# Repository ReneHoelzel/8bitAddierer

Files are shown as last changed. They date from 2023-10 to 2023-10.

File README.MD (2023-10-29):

# 8bit Addierer

Das Projekt wurde in Zusammenarbeit mit dem Zuseum in Bautzen entwickelt und soll Schülern und interessierten die Rechenweise eine Computers anhand eines Bytes (=8bit) veranschaulichen. 

## Aufbau

Im unteren Bereich befindet sich ein Arduino Nano V3 als Steuereinheit sowie 8x Doppelpins an die je ein Taster angeschlossen werden kann. Ein Anschlus für den neunten Taster (Erläterung siehe Funktion) befindet sich unter dem Arduino.<br/>

## Funktion

Mit den 8 Tastern kann die dazugehörige 7-Segment Anzeige/rote LED jeweils ein- oder ausgeschalten werden. Je nachdem welche "Bits" eingeschalten sind wird oben in der 3-stelligen Anzeige der entsprechende Wert als Ganzzahl (Byte) ausgegeben.

Zum Beispiel: 0 0 0 0 1 0 0 1 entspricht dem Wert 9.

Mit dem neunten Taster kann das Ergebnis "ausgeblendet" werden (es wird der Wert 999 angezeigt). Dies kann verwendet werden, um einen Wert einzustellen und die Schüler herausfinden zu lassen welcher Byte-Wert sich dahinter verbirgt.

<br/>

<span style="color:red;">Die Verwendung erfolgt auf eigene Gefahr.<span/>

Zum Arduino Programm geht es [hier](https://github.com/ReneHoelzel/8bitAddierer/tree/main/Program).

Es gibt aktuell 2 Board Revisionen:

- [Revision A](8BitZahlAnzeige_RevA/README.MD)

- [Revision B](8BitZahlAnzeige_RevB/README.MD)

Der Unterschied zu beiden Versionen ist, dass bei Revision B die 8x 7-Segment Anzeige und der MAX7219 Steuerchip die Positionen getauscht haben.

## ToDo

- Gehäuse entwerfen

- Animation der 3-stelligen Anzeige, wenn der neunte Taster gedrückt ist.

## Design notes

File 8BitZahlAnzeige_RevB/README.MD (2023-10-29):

# 8bit Addierer

##### Revision B

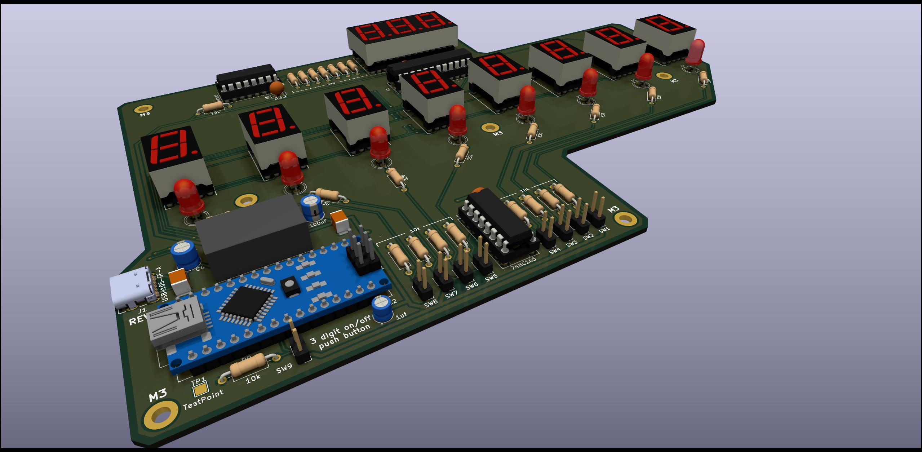
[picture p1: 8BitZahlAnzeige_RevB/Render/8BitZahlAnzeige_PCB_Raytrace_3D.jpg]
3D Ansicht


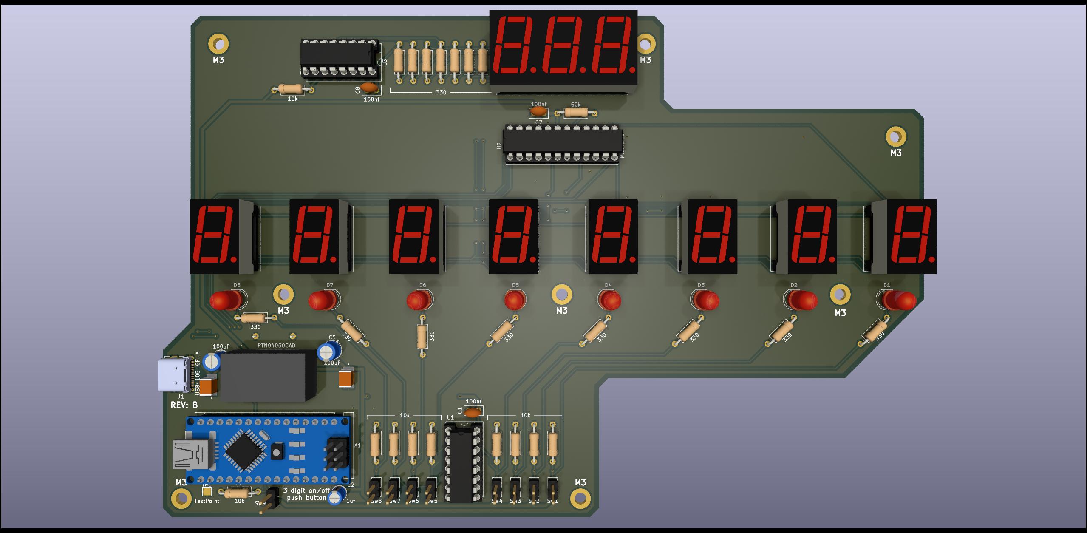
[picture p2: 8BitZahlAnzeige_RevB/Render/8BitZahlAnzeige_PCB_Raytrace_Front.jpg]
Front Ansicht bestückt Vorderseite bestückt


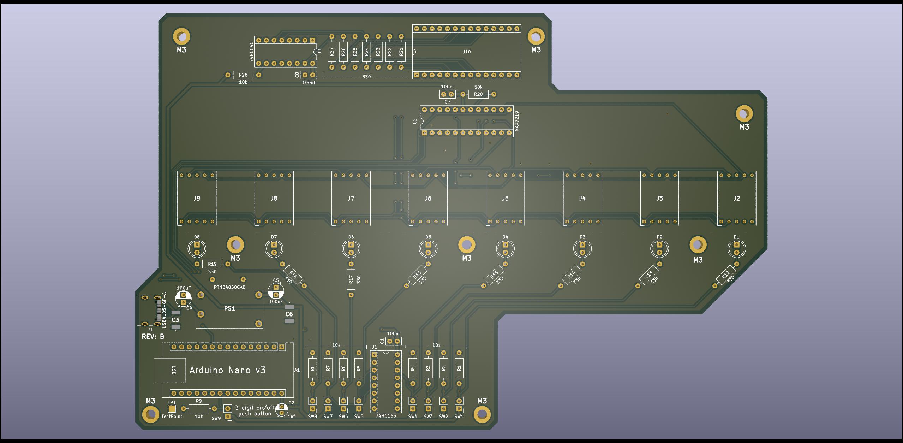
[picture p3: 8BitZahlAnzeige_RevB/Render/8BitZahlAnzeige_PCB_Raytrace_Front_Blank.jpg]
Vorderseite


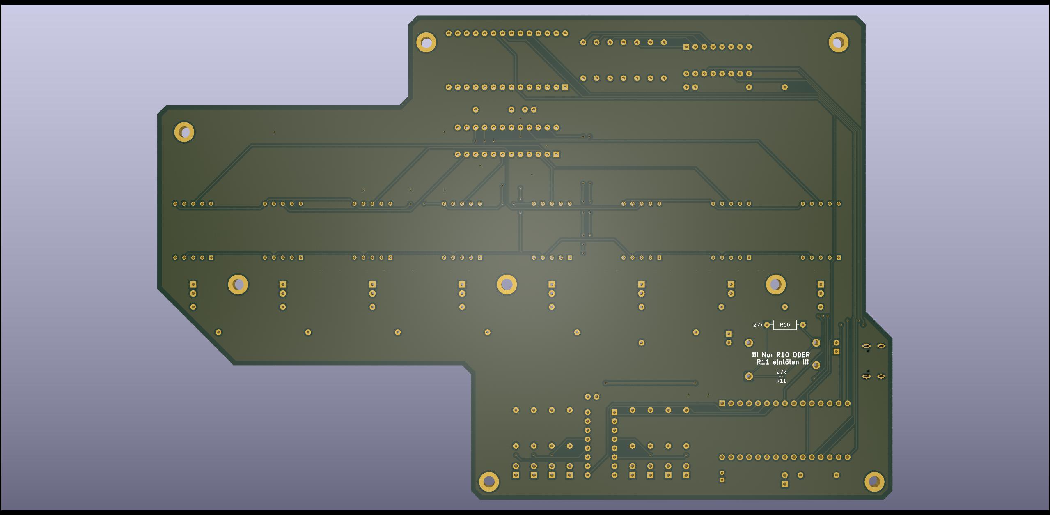
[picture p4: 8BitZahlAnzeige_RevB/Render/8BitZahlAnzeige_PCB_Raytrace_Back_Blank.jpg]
Rückseite 3D Rückseite


[Zurück zur Startseite](https://github.com/ReneHoelzel/8bitAddierer/tree/main)

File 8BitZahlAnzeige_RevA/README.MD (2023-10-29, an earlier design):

# 8bit Addierer

##### Revision A

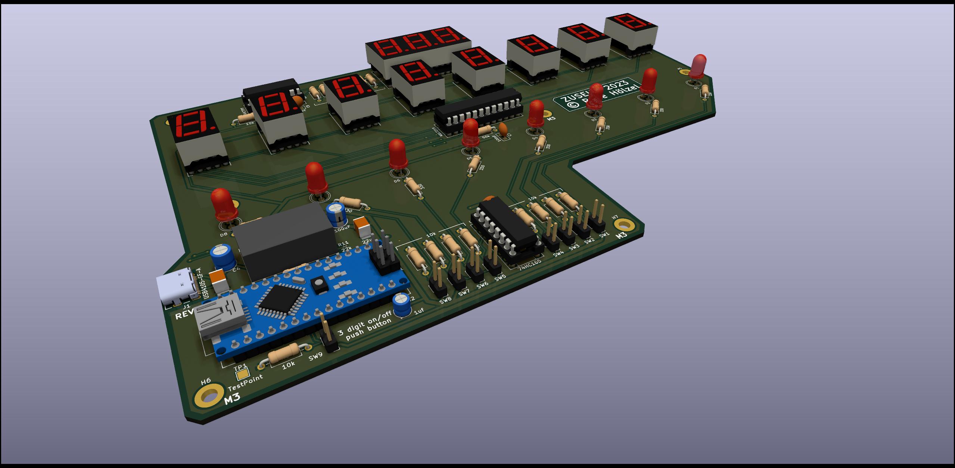
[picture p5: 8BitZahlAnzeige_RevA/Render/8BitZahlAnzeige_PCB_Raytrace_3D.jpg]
3D Ansicht bestückt


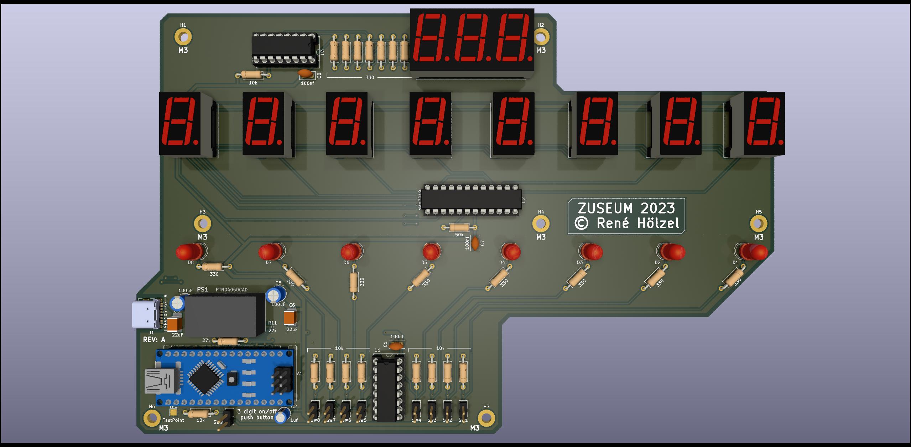
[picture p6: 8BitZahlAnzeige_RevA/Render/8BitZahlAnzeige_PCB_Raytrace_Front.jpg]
Front Ansicht bestückt


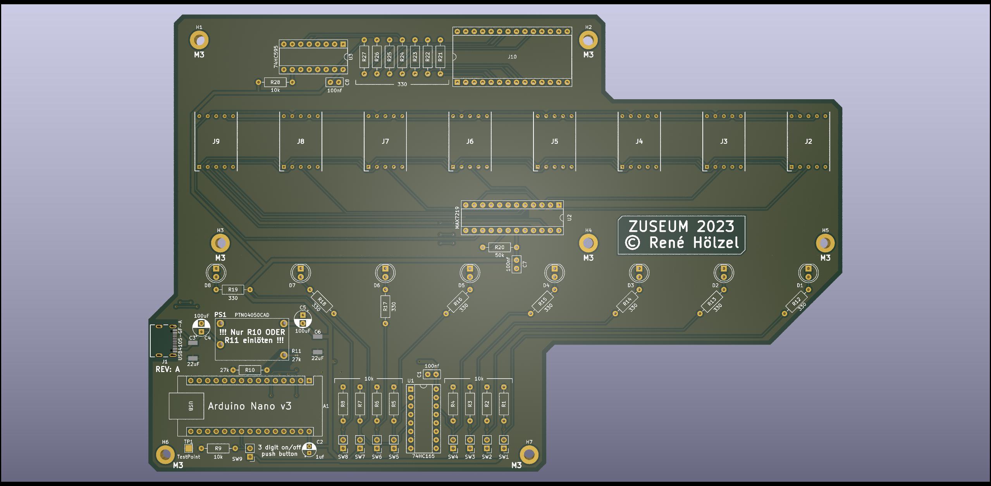
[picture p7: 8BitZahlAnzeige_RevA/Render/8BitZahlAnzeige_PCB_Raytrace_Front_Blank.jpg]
Vorderseite Frontansicht


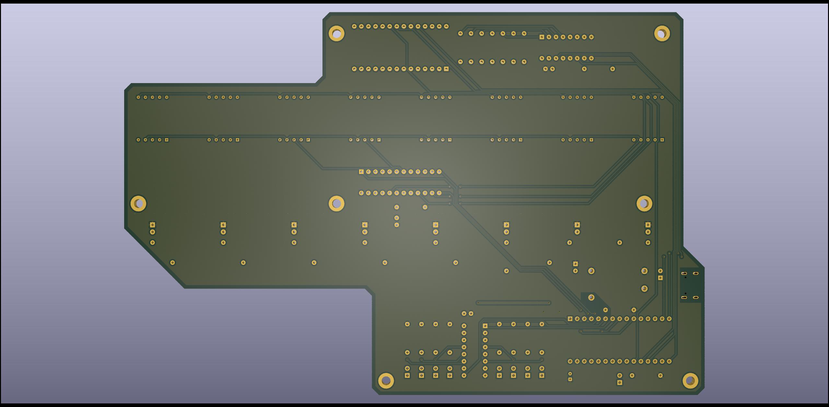
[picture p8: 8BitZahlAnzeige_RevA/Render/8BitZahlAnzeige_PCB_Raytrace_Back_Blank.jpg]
Rückseite Rückansicht


[Zurück zur Startseite](https://github.com/ReneHoelzel/8bitAddierer/tree/main)

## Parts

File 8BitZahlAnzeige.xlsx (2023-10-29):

Anzahl Platinen: | 6
Anzahl pro Platine | Anzahl benötigt gesamt | Referenz auf Platine | Bezeichnung | Verpackung Menge | Verpackung Preis | Gesamtpreis | Beispiel Bild | Link | Lieferant | Bestellt Anzahl | Bestellt Preis
1 | 6 | A1 | Arduino Nano v3 | 3 | 19.79 € | 39.58 € |  | https://www.amazon.de/3Pack-MEGA328P-AU-Micro-Controller-Entwicklungsboard-USB-Kabel/dp/B0C4H3LXKN | Amazon | 2 | 48.48 €
9 | 54 | SW1, SW2, SW3, SW4, SW5, SW6, SW7, SW8, SW9 | Drucktaster | 20 | 9.65 € | 28.95 € |  | https://www.amazon.de/gp/product/B0BY12RR6Z | Amazon | 2 | 28.20 €
1 | 6 | U1 | 74HC165 | 10 | 19.91 € | 19.91 € |  | https://www.amazon.de/gp/product/B0CBP8VNW3 | Amazon | 0 | 8.90 €
1 | 6 | U2 | MAX7219 | 10 | 36.33 € | 36.33 € |  | https://www.amazon.de/gp/product/B07FW17ZW8/ref=ppx_od_dt_b_asin_title_s00?ie=UTF8&psc=1 | Amazon | 0 | 8.90 €
1 | 6 | U3 | 74HC595 | 10 | 6.50 € | 6.50 € |  | https://www.amazon.de/HeyNana-SN74HC595N-Register-74HC595-DIP-16/dp/B093Y2MQGV | Amazon | 0 | 8.90 €
9 | 54 | SW1, SW2, SW3, SW4, SW5, SW6, SW7, SW8, SW9 |  | 80 | 1.00 € | 1.00 € |  | https://www.amazon.de/gp/product/B07VGF34KX/ref=ppx_yo_dt_b_asin_title_o07_s00?ie=UTF8&psc=1 | Amazon | 0 | 8.90 €
1 | 6 | J1 |  | 1 | 0.95 € | 5.70 € |  | https://www.amazon.de/gp/product/B09JZX2SBL | Amazon | 4 | 12.70 €
8 | 48 | J2, J3, J4, J5, J6, J7, J8, J9 |  | 10 | 9.30 € | 46.50 € |  | https://www.amazon.de/gp/product/B07CLCC82N | Amazon | 3 | 36.80 €
3 | 18 | C1, C7, C8 | 100nf (=0,1uF) | 1 | 0.13 € | 2.34 € |  | https://www.conrad.de/de/p/weltron-keramik-kondensator-radial-bedrahtet-0-1-f-50-v-dc-20-b-x-h-5-08-mm-x-5-08-mm-1-st-453358.html | Conrad | 20 | 11.50 €
1 | 6 | C2 | 1uf | 1 | 0.04 € | 0.26 € |  | https://www.conrad.de/de/p/teapo-kss105m063s1a5b07k-elektrolyt-kondensator-radial-bedrahtet-1-5-mm-1-f-6-3-v-20-o-x-h-4-mm-x-7-mm-1-st-1325878.html | Conrad | 0 | 8.90 €
2 | 12 | C4, C5 | 100uF | 1 | 0.06 € | 0.78 € |  | https://www.conrad.de/de/p/teapo-ksy107m025s1a5e11k-elektrolyt-kondensator-radial-bedrahtet-2-5-mm-100-f-25-v-10-o-x-h-6-3-mm-x-11-mm-1-st-1301761.html | Conrad | 12 | 9.68 €
8 | 48 | D1, D2, D3, D4, D5, D6, D7, D8 | LED | 1 | 0.13 € | 6.24 € |  | https://www.conrad.de/de/p/tru-components-1573741-led-bedrahtet-rot-rund-5-mm-1300-mcd-50-20-ma-2-1-v-1573741.html | Conrad | 50 | 15.40 €
10 | 60 | R1, R2, R3, R4, R5, R6, R7, R8, R9, R28 | 10k | 100 | 2.79 € | 2.79 € |  | https://www.conrad.de/de/p/quadrios-22p119-22p119-kohleschicht-widerstand-sortiment-10-k-axial-bedrahtet-0-5-w-5-1-set-2620471.html | Conrad | 1 | 11.69 €
15 | 90 | R12, R13, R14, R15, R16, R17, R18, R19, R21, R22, R23, R24, R25, R26, R27 | 330 | 100 | 2.79 € | 2.79 € |  | https://www.conrad.de/de/p/quadrios-22p113-22p113-kohleschicht-widerstand-sortiment-330-axial-bedrahtet-0-5-w-5-1-set-2620465.html | Conrad | 1 | 11.69 €
1 | 6 | R20 | 50k | 1 | 0.05 € | 0.30 € |  | https://www.conrad.de/de/p/weltron-405469-kohleschicht-widerstand-56-k-axial-bedrahtet-0411-0-5-w-5-1-st-405469.html | Conrad | 20 | 9.89 €
9 | 54 | SW1, SW2, SW3, SW4, SW5, SW6, SW7, SW8, SW9 | Stiftleisten für Taster | 1 | 0.07 € | 3.84 € |  | https://www.conrad.de/de/p/mpe-garry-stiftleiste-standard-anzahl-reihen-1-polzahl-je-reihe-2-087-1-002-0-s-xs0-1260-1-st-733900.html | Conrad | 100 | 16.01 €
2 | 12 | C3, C6 | 22uF | 1 | 0.89 € | 10.72 € |  | https://www.mouser.de/ProductDetail/TDK/C4532X7R1C226M230KB?qs=LcTL%2F5vFEzGnHgbQAdlvvg%3D%3D | Mouser | 10 | 17.83 €
1 | 6 | J1 | USB4105-GF-A | 1 | 0.74 € | 4.46 € |  | https://www.mouser.de/ProductDetail/GCT/USB4105-GF-A?qs=KUoIvG%2F9IlY%2FMLlBMpStpA%3D%3D | Mouser | 10 | 16.34 €
8 | 48 | J2, J3, J4, J5, J6, J7, J8, J9 | 110-87-610-41-001101 | 1 | 0.66 € | 31.44 € |  | https://www.mouser.de/ProductDetail/437-1108761041001101 | Mouser | 28 | 27.24 €
1 | 6 | J10 | 110-87-628-41-001101 | 1 | 2.02 € | 12.12 € |  | https://www.mouser.de/ProductDetail/437-1108762841001101 | Mouser | 4 | 16.98 €
1 | 6 | PS1 | PTN04050CAD | 1 | 16.79 € | 100.74 € |  | https://www.mouser.de/ProductDetail/Texas-Instruments/PTN04050CAD?qs=sSOk4GDDv7z3sgPhmEmGQg%3D%3D | Mouser | 3 | 59.27 €
1 | 6 | R10 | 27k | 1 | 0.55 € | 3.29 € | Auf Rückseite direkt an Pin 1 + 3 anlöten (Nur Rev: A) | https://www.mouser.de/ProductDetail/Vishay-Dale/RN55D2702FB14?qs=I4Va0YTo0cN6RqYg6k%2FfEQ%3D%3D | Mouser | 10 | 14.39 €
1 | 6 | R11 | 27k | 1 | 0.10 € | 0.61 € |  |  | Mouser | 0 | 8.90 €
 |  |  |  |  |  | 367.19 € |  |  |  |  | 417.49 €

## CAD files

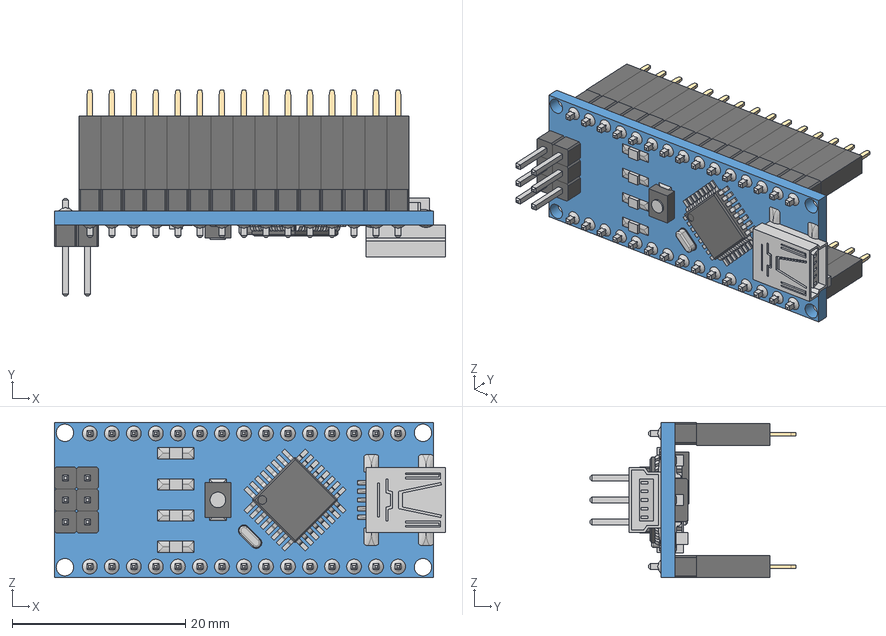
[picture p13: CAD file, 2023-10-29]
3DModels/Arduino_Nano_V3_with_Female_Header/Arduino NanoV3 + Female Headers.step
45.1 x 23.7 x 17.9 mm
switch
Led x 3
Led (1)
Pin x 21
chip1
USB
Crystal
Pin (1) x 15
Res x 5
cap x 2
Chip
respack x 2
diode
vreg
HF1 x 30

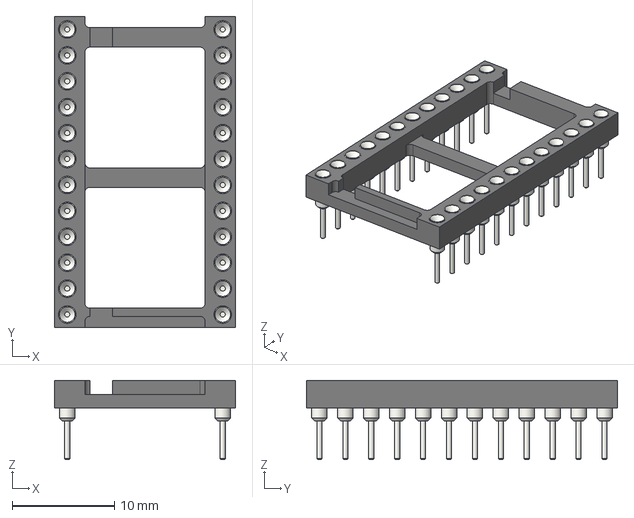
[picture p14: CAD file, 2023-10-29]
3DModels/dip_10_W15.24mm/DIP-10_W15.24mm_Socket.step
17.8 x 30.5 x 7.79 mm

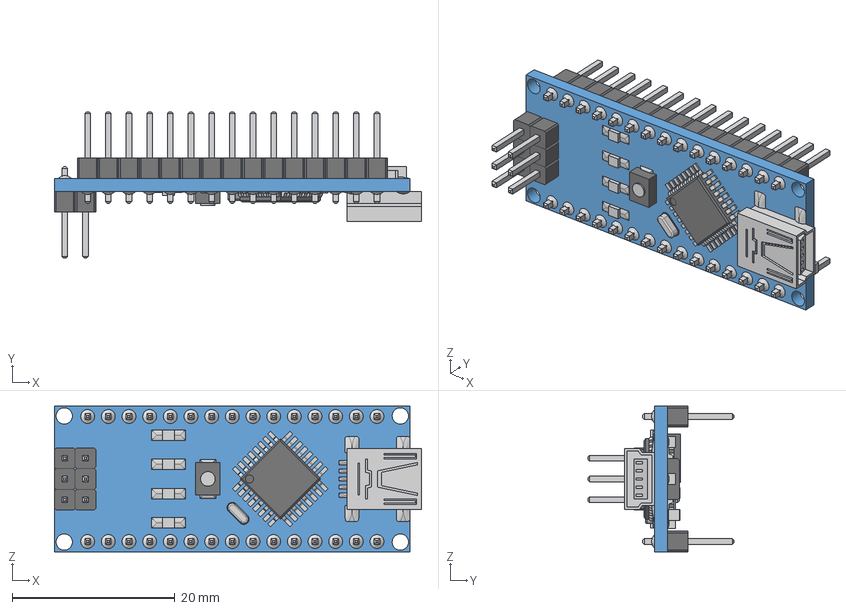
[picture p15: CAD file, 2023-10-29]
3DModels/Arduino_Nano_V3_with_Female_Header/Arduino Nano V3.step
45.1 x 18.0 x 17.9 mm
switch
Led x 3
Led (1)
Pin x 21
chip1
USB
Crystal
Pin (1) x 15
Res x 5
cap x 2
Chip
respack x 2
diode
vreg

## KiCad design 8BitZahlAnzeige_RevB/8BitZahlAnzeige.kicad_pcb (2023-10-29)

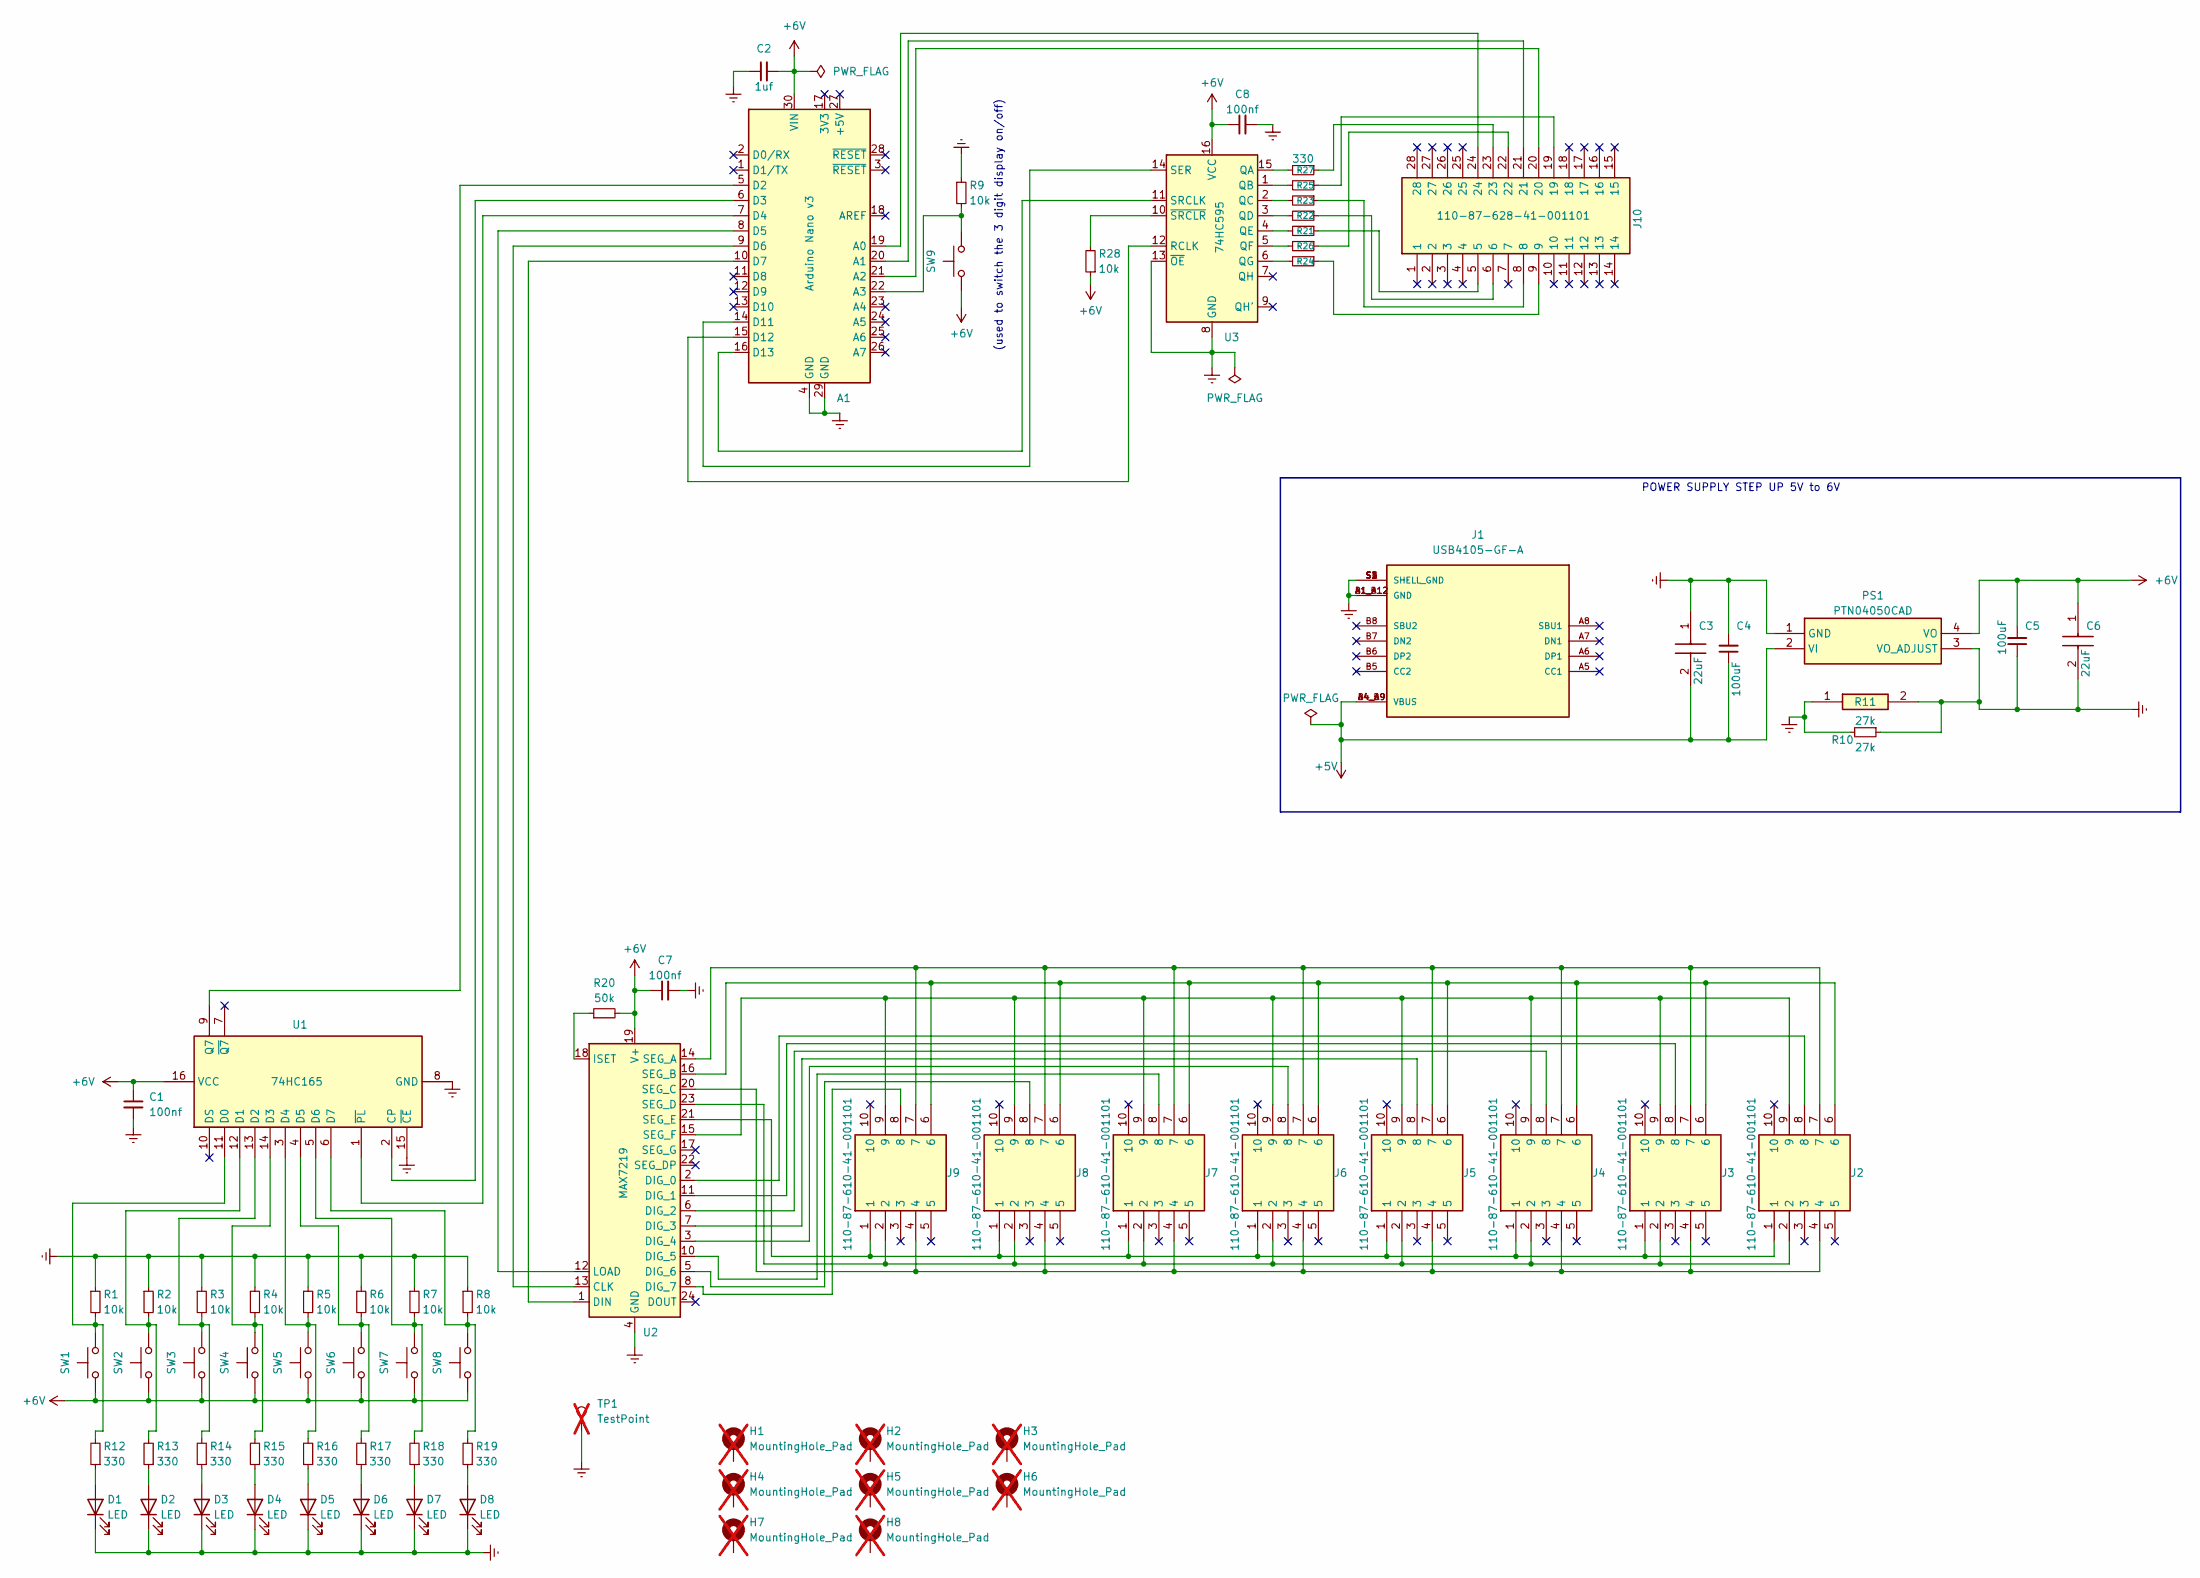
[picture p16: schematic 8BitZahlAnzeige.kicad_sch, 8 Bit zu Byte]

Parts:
A1: Arduino Nano v3; Arduino_Nano
C1, C7, C8: 100nf; C_Disc_D5.0mm_W2.5mm_P2.50mm
C2: 1uf; CP_Radial_D4.0mm_P2.00mm
C3, C6: 22uF; C4532_Commercial; Mouser Part Number 810-C4532X7R1C226M10
C4, C5: 100uF; CP_Radial_D5.0mm_P2.50mm
D1, D2, D3, D4, D5, D6, D7, D8: LED; LED_D5.0mm
H1, H2, H3, H4, H5, H6, H7, H8: MountingHole_Pad; MountingHole_3.2mm_M3_DIN965_Pad; not fitted
J1: USB4105-GF-A; GCT_USB4105-GF-A; PARTREV A3
J2, J3, J4, J5, J6, J7, J8, J9: 110-87-610-41-001101; DIPS1524W50P254L1270H370Q10N; Mouser Part Number 437-1108761041001101
J10: 110-87-628-41-001101; DIP-28_W15.24mm_Socket; Mouser Part Number 437-1108762841001101
PS1: PTN04050CAD; PTN04050CAH; Manufacturer_Part_Number PTN04050CAD; Mouser Part Number 595-PTN04050CAD
R1, R2, R3, R4, R5, R6, R7, R8, R9, R28: 10k; R_Axial_DIN0207_L6.3mm_D2.5mm_P10.16mm_Horizontal
R10: 27k; R_Axial_DIN0207_L6.3mm_D2.5mm_P10.16mm_Horizontal
R11: 27k; R_0201_0603Metric; Mouser Part Number 660-RK73H1HTTC2702F
R12, R13, R14, R15, R16, R17, R18, R19, R21, R22, R23, R24, R25, R26, R27: 330; R_Axial_DIN0207_L6.3mm_D2.5mm_P10.16mm_Horizontal
R20: 50k; R_Axial_DIN0207_L6.3mm_D2.5mm_P10.16mm_Horizontal
SW1, SW2, SW3, SW4, SW5, SW6, SW7, SW8, SW9: SW_Push; PinHeader_1x02_P2.54mm_Vertical
TP1: TestPoint; TestPoint_Pad_2.0x2.0mm; not fitted
U1: 74HC165; DIP-16_W7.62mm_Socket
U2: MAX7219; DIP-24_W7.62mm_Socket
U3: 74HC595; DIP-16_W7.62mm_Socket

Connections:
+5V: C3.2, C4.1, J1.A4_B9 (VBUS), J1.B4_A9 (VBUS), PS1.2 (VI)
+6V: A1.30 (VIN), C1.1, C2.2, C5.2, C6.1, C7.1, C8.1, PS1.4 (VO), R20.2, R28.1, SW1.1, SW2.1, SW3.1, SW4.1, SW5.1, SW6.1, SW7.1, SW8.1, SW9.1, U1.16 (VCC), U2.19 (V+), U3.16 (VCC)
GNDREF: A1.4 (GND), A1.29 (GND), C1.2, C2.1, C3.1, C4.2, C5.1, C6.2, C7.2, C8.2, D1.1 (K), D2.1 (K), D3.1 (K), D4.1 (K), D5.1 (K), D6.1 (K), D7.1 (K), D8.1 (K), J1.A1_B12 (GND), J1.B1_A12 (GND), J1.S1 (SHELL_GND), J1.S2 (SHELL_GND), J1.S3 (SHELL_GND), J1.S4 (SHELL_GND), PS1.1 (GND), PS1.3 (VO_ADJUST), R1.1, R2.1, R3.1, R4.1, R5.1, R6.1, R7.1, R8.1, R9.1, R10.1, R10.2, R11.1, R11.2, TP1.1, U1.8 (GND), U1.15 (~CE), U2.4 (GND), U2.9 (GND), U3.8 (GND), U3.13 (~OE)
unnamed: A1.19 (A0), J10.24
unnamed: A1.20 (A1), J10.21
unnamed: A1.21 (A2), J10.20
unnamed: A1.22 (A3), R9.2, SW9.2
unnamed: A1.5 (D2), U1.9 (Q7)
unnamed: A1.6 (D3), U1.2 (CP)
unnamed: A1.7 (D4), U1.1 (~PL)
unnamed: A1.8 (D5), U2.12 (LOAD)
unnamed: A1.9 (D6), U2.13 (CLK)
unnamed: A1.10 (D7), U2.1 (DIN)
unnamed: A1.14 (D11), U3.14 (SER)
unnamed: A1.15 (D12), U3.12 (RCLK)
unnamed: A1.16 (D13), U3.11 (SRCLK)
unnamed: D1.2 (A), R12.1
unnamed: D2.2 (A), R13.1
unnamed: D3.2 (A), R14.1
unnamed: D4.2 (A), R15.1
unnamed: D5.2 (A), R16.1
unnamed: D6.2 (A), R17.1
unnamed: D7.2 (A), R18.1
unnamed: D8.2 (A), R19.1
unnamed: J10.5, R21.1
unnamed: J10.6, R22.1
unnamed: J10.8, R23.1
unnamed: J10.9, R24.1
unnamed: J10.19, R25.1
unnamed: J10.22, R26.1
unnamed: J10.23, R27.1
unnamed: R1.2, R12.2, SW1.2, U1.11 (D0)
unnamed: R2.2, R13.2, SW2.2, U1.12 (D1)
unnamed: R3.2, R14.2, SW3.2, U1.13 (D2)
unnamed: R4.2, R15.2, SW4.2, U1.14 (D3)
unnamed: R5.2, R16.2, SW5.2, U1.3 (D4)
unnamed: R6.2, R17.2, SW6.2, U1.4 (D5)
unnamed: R7.2, R18.2, SW7.2, U1.5 (D6)
unnamed: R8.2, R19.2, SW8.2, U1.6 (D7)
unnamed: J2.8, U2.2 (DIG_0)
unnamed: J3.8, U2.11 (DIG_1)
unnamed: J4.8, U2.6 (DIG_2)
unnamed: J5.8, U2.7 (DIG_3)
unnamed: J6.8, U2.3 (DIG_4)
unnamed: J7.8, U2.10 (DIG_5)
unnamed: J8.8, U2.5 (DIG_6)
unnamed: J9.8, U2.8 (DIG_7)
unnamed: R20.1, U2.18 (ISET)
unnamed: J2.7, J3.7, J4.7, J5.7, J6.7, J7.7, J8.7, J9.7, U2.14 (SEG_A)
unnamed: J2.6, J3.6, J4.6, J5.6, J6.6, J7.6, J8.6, J9.6, U2.16 (SEG_B)
unnamed: J2.4, J3.4, J4.4, J5.4, J6.4, J7.4, J8.4, J9.4, U2.20 (SEG_C)
unnamed: J2.2, J3.2, J4.2, J5.2, J6.2, J7.2, J8.2, J9.2, U2.23 (SEG_D)
unnamed: J2.1, J3.1, J4.1, J5.1, J6.1, J7.1, J8.1, J9.1, U2.21 (SEG_E)
unnamed: J2.9, J3.9, J4.9, J5.9, J6.9, J7.9, J8.9, J9.9, U2.15 (SEG_F)
unnamed: R27.2, U3.15 (QA)
unnamed: R25.2, U3.1 (QB)
unnamed: R23.2, U3.2 (QC)
unnamed: R22.2, U3.3 (QD)
unnamed: R21.2, U3.4 (QE)
unnamed: R26.2, U3.5 (QF)
unnamed: R24.2, U3.6 (QG)
unnamed: R28.2, U3.10 (~SRCLR)

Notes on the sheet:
(used to switch the 3 digit display on/off)
POWER SUPPLY STEP UP 5V to 6V

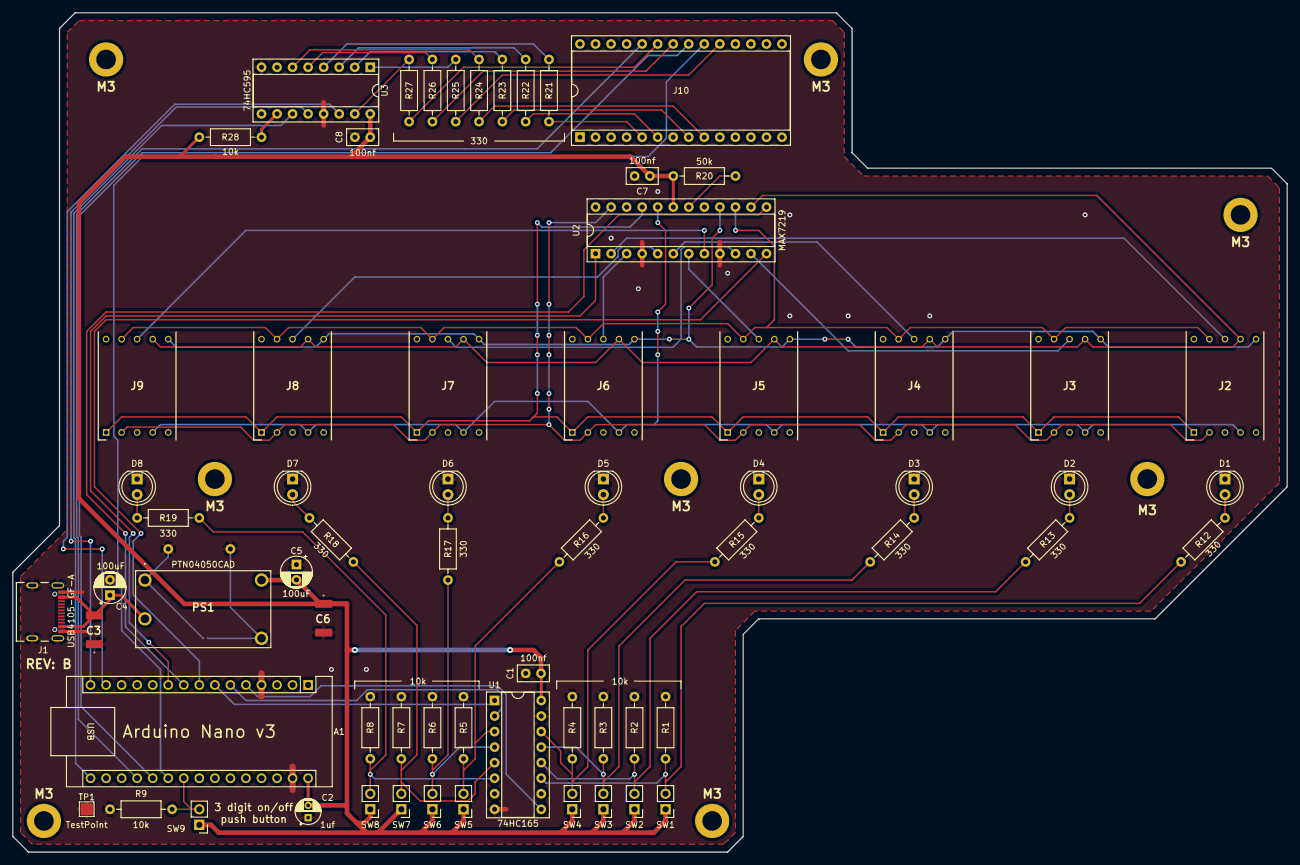
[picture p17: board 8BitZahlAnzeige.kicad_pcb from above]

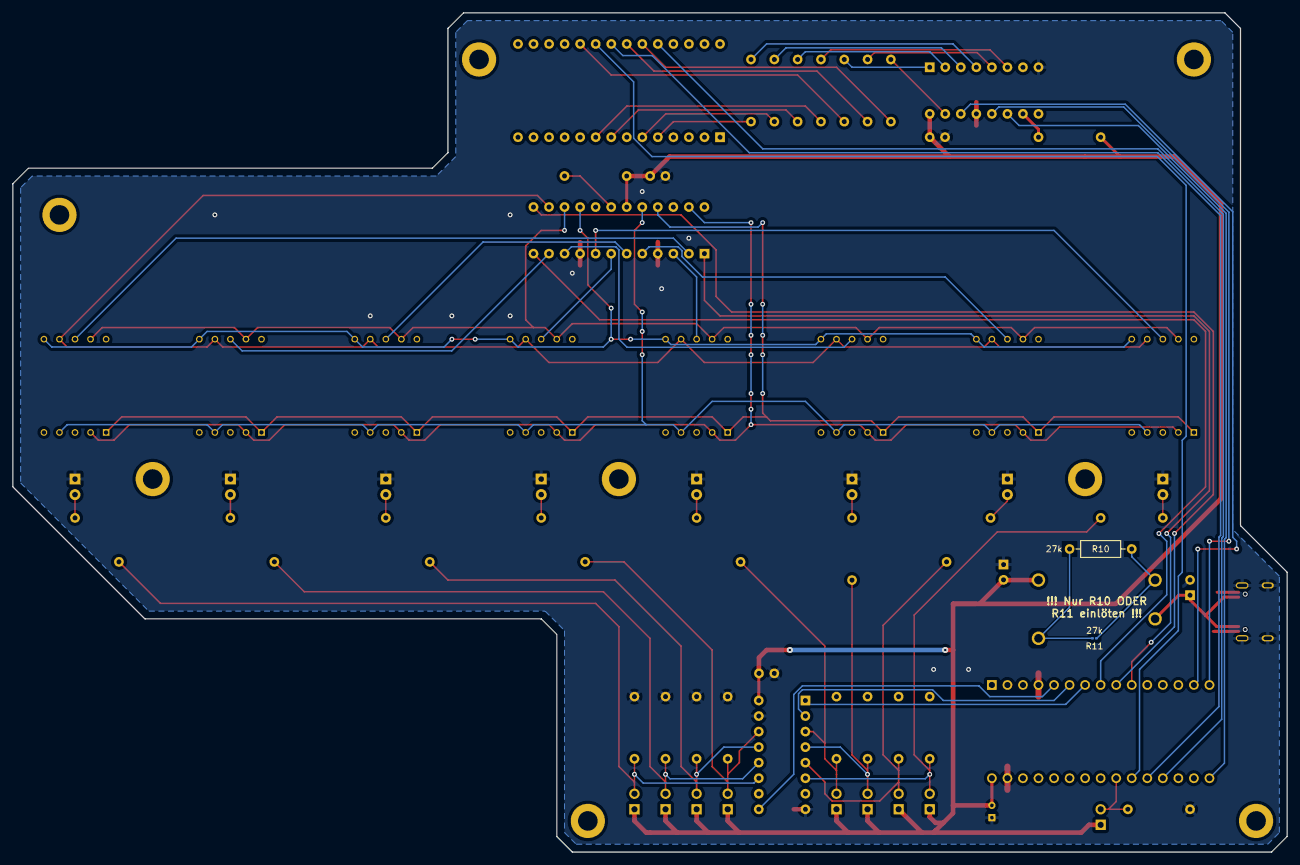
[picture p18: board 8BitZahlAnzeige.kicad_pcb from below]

Board: 2 copper layers, 208.3 x 137.2 mm, 77 parts (2 on the bottom side), 62 nets.

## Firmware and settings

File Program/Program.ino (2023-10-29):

#include <LedControl.h>
#include <SevSegShift.h>

// Source: https://www.woolseyworkshop.com/2021/02/18/adding-digital-io-to-your-arduino-part-2-the-74hc165/
const unsigned long SamplePeriod = 250;  // Sampling period in milliseconds

const int dOffPin = A3;  // Used to show or hide the the final byte value (3 segment display)

// Variables for the 74HC165 that reads the 8 switches
const int dataPin1 = 2;   // Connected to 74HC165 QH    (pin 9)
const int clockPin1 = 3;  // Connected to 74HC165 CLK   (pin 2)
const int latchPin1 = 4;  // Connected to 74HC165 SH/LD (pin 1)

// Variables for the MAX7219 to visualize 0 or 1 (8x 7Segment)
const int latchPin2 = 5;  // Connected to MAX7219 DIN   (pin 12)
const int clockPin2 = 6;  // Connected to MAX7219 CLK  (pin 13)
const int dataPin2 = 7;   // Connected to MAX7219 LOAD (pin 1)

// Initialize Led control library
// http://wayoda.github.io/LedControl/pages/software
LedControl lc = LedControl(dataPin2, clockPin2, latchPin2, 1);

// Variables for the 3 digit 7 segment display
const int dataPin4 = 11;   // Connected to 74HC595 SER  (pin 14)
const int latchPin4 = 12;  // Connected to 74HC595 RCLK (pin 12)
const int clockPin4 = 13;  // Connected to 74HC595 SRLCK (pin 11)

// Instantiate a seven segment controller object
/* 1 = number of shift registers used
   true = Digits are connected to Arduino directly default value = false (see SevSegShift example)
*/
SevSegShift sevsegshift(dataPin4, clockPin4, latchPin4, 1, true);

int zeroOneSegments;
int zeroOneSegmentsOld;

void setup() {
  // Serial Monitor
  //Serial.begin(115200);  // initialize serial bus
  //while (!Serial) ;  // wait for serial connection

  // Button to show/hide final byte value
  pinMode(dOffPin, INPUT);

  // 74HC165 shift register (8x buttons/switches)
  pinMode(dataPin1, INPUT);
  pinMode(latchPin1, OUTPUT);
  pinMode(clockPin1, OUTPUT);

  /* The MAX72XX is in power-saving mode on startup, we have to do a wakeup call */
  lc.shutdown(0, false);
  /* Set the brightness to a medium values (max = 15) */
  lc.setIntensity(0, 3);
  /* Clear the display */
  lc.clearDisplay(0);

  setupSevSeg();
}

void setupSevSeg() {
  byte numDigits = 3;
  byte digitPins[] = { A0, A1, A2 };                // These are the PINS of the ** Arduino **
  byte segmentPins[] = { 0, 1, 2, 3, 4, 5, 6, 7 };  // These are the PINs of the ** Shift register **
  bool resistorsOnSegments = true;                  // 'false' means resistors are on digit pins
  byte hardwareConfig = COMMON_CATHODE;             // See README.md for options
  bool updateWithDelays = false;                    // Default 'false' is Recommended
  bool leadingZeros = false;                        // Use 'true' if you'd like to keep the leading zeros
  bool disableDecPoint = true;                      // Use 'true' if your decimal point doesn't exist or isn't connected

  sevsegshift.begin(hardwareConfig, numDigits, digitPins, segmentPins, resistorsOnSegments,
                    updateWithDelays, leadingZeros, disableDecPoint);
  sevsegshift.setBrightness(90);
}

void loop() {
  // Read and print inputs at the specified sampling rate
  static unsigned long previousTime = 0;
  unsigned long currentTime = millis();
  if (currentTime - previousTime >= SamplePeriod) {
    readButtonStates();
    previousTime = currentTime;

    // Draw 0 or 1 in each segment
    segmentLine_MAX7219();
  }

  // Draw the byte number (0-255)
  sevSegWrite();
}

void readButtonStates() {
  // Always reset
  zeroOneSegments = 0;

  // Read
  //Serial.print("Bits: ");
  for (int i = 0; i < 8; i++) {
    int state = isrDigitalRead(i);
    zeroOneSegments |= state << i;
  }
  //Serial.println(zeroOneSegments);
}

// Source: https://www.woolseyworkshop.com/2021/02/18/adding-digital-io-to-your-arduino-part-2-the-74hc165/
uint8_t isrReadRegister() {
  uint8_t inputs = 0;
  digitalWrite(clockPin1, HIGH);                    // preset clock to retrieve first bit
  digitalWrite(latchPin1, HIGH);                    // disable input latching and enable shifting
  inputs = shiftIn(dataPin1, clockPin1, MSBFIRST);  // capture input values
  digitalWrite(latchPin1, LOW);                     // disable shifting and enable input latching
  return inputs;
}

// Source: https://www.woolseyworkshop.com/2021/02/18/adding-digital-io-to-your-arduino-part-2-the-74hc165/
int isrDigitalRead(uint8_t pin) {
  return bitRead(isrReadRegister(), pin);
}

void segmentLine_MAX7219() {
  /* 
  * Display a character on a 7-Segment display.
  * There are only a few characters that make sense here :
  * '0','1','2','3','4','5','6','7','8','9','0',
  * 'A','b','c','d','E','F','H','L','P',
  * '.','-','_',' ' 
  * Params:
  * addr	 address of the display (0 if only one is used else index)
  * digit  the position of the character on the display (0..7)
  * value  the character to be displayed. 
  * dp     sets the decimal point.
  *
  * lc.setDigit(addr, digit, value, dp);
  */

  for (int digit = 0; digit < 8; digit++) {
    lc.setDigit(0, digit, (zeroOneSegments >> digit) & 1, false);
    //Serial.print(digit);
  }

  //Serial.println("");
  lc.shutdown(0, false);
}

void sevSegWrite() {
  if (digitalRead(dOffPin) == LOW) {
    // ToDo: Animation?
    sevsegshift.setNumber(999);
  } else {
    sevsegshift.setNumber(zeroOneSegments);
  }
  sevsegshift.refreshDisplay();  // Must run repeatedly
}

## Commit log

2023-10-29 Initial Upload
    [8BitZahlAnzeige.kicad_pcb, 8BitZahlAnzeige.kicad_sch, 8BitZahlAnzeige.xlsx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]
2023-10-29 Bilder und Readme's aktualisiert
2023-10-29 - Ignorieren automatisch generierter Backup-Ordner - Anpassen der Leitungen im Rev B Layout
    [8BitZahlAnzeige.kicad_pcb]

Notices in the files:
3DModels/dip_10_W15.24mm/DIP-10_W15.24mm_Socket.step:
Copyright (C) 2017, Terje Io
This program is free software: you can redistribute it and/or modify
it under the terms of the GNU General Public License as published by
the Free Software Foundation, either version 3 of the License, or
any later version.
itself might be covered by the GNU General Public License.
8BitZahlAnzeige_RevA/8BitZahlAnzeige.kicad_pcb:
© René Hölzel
